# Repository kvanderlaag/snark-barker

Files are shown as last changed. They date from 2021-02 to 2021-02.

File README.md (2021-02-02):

# The Shark Barber - a silly joke that is a rebadge of the Snark Barker - a SB 1.0 Clone

## The Shark Barber
Literally all I did was change some silkscreen graphics to make the card look 
sillier. My wife misread "Snark Barker" as "Shark Barber" while I was looking 
at the PCB layout to find a component reference while building mine, and
[@leadedsolder](https://twitter.com/LeadedSolder) suggested that it needed a
cartoon of a shark on it. Otherwise, this is 100% Snark Barker and you should
check out Eric's documentation because it's fantastic.

## The Snark Barker
The Snark Barker is a 100% compatible clone of the famed SB 1.0 "Killer Card"
sound card from 1989. It implements all the features, including the digital
sound playback and recording, Ad Lib compatible synthesis, the joystick/MIDI
port, and the CMS chips (which are actually Philips SAA1099 synthesizer
devices).

Snark Barker photo

All of the components are readily available. In the bill of materials,
Mouser part numbers are listed where they are available. Chips not available
from Mouser can be purchased from a variety of sources in China.

[Schematic](https://github.com/schlae/snark-barker/blob/master/SnarkBarker.pdf)

[Bill of Materials](https://github.com/schlae/snark-barker/blob/master/SnarkBarker.csv)

Please note that the 0.1" header pins are *not* listed on the BOM. They are
standard breakaway headers (both single and double row). Jumper shunts are
also not listed on the BOM.

[Fab files](https://github.com/schlae/snark-barker/blob/master/fab/SnarkBarker.zip)

Board dimensions are 9.1 x 4.2 inches. When ordering the board, you may want
to specify a card edge bevel (fairly cheap!) and selective gold plating
(expensive!) depending on your needs. The soldermask color can be whatever
you like, but hot pink is preferred.

## The Volume Knob
There don't seem to be any off-the-shelf knobs compatible with the Alps
potentiometer. You may be able to 3D print one based on the model below.
I'd recommend using a high-resolution SLA printer like the Formlabs Form 2.

Fasten it to the potentiometer using an M1.4x0.3mm thread, 6mm long screw
(McMaster-Carr part number 91800A036 or equivalent).

Image of the volume knob

[Volume knob STEP model](https://github.com/schlae/snark-barker/blob/master/mech/vol_knob.zip)

Update: I've added a modified volume knob that may print better on FDM
printers.

[Volume knob STEP model, FDM version](https://github.com/schlae/snark-barker/blob/master/mech/vol_knob_fdm.zip)

## The ISA Card Bracket
The bracket specified in the BOM is a blank Keystone 9200 bracket. You will
need to punch or drill holes for the connectors. The KiCad board file has
detailed dimensions showing where to make the holes in the bracket.

I use a chassis nibbler tool to make the square slot for the volume knob as
well as the hole for the DA-15 joystick/MIDI connector. If you are rich,
Greenlee makes a punch for the DA-15 outline.

## The Firmware
There are two ways to get a programmed 80C51 chip for the Snark Barker. One
is to purchase a SB 2.0 DSP chip from China and put it in a 44-PLCC to
40-DIP adapter. This works fine and provides the largest feature set.

Another option is to buy a blank Atmel 89S51 (as listed in the BOM) and
program it with [this HEX file](https://github.com/schlae/snark-barker/blob/master/firmware/sb.hex).

## Assembly Notes
You may wish to socket the two CMS chips, the 80C51 microcontroller, and the
two Yamaha chips.

Be sure to add the 4.7K ohm bodge resistor on top of U5, running between
pins 4 and 14. (Shown below.)

Photo of bodge resistor

For MIDI to work properly, you'll need to solder jumper wires on the headers
marked TXD and RXD (next to the SNARK BARKER logo). Originally these two 3-pin
headers may have been used as a debug port.

Be sure to place shunts in the jumpers marked DRQ1 and JP1, to enable DMA and
the joystick, respectively. Also place shunts to configure the I/O address and
IRQ.

## Testing and Diagnostics
Test your shiny new card using your favorite PC games, or use the [SBDIAG
program that I've written](https://github.com/schlae/snark-barker/tree/master/sbdiag).

## Other Notes
Like the original SB 1.0, the Snark Barker does not need a -5V rail.

## License
This work is licensed under a Creative Commons Attribution-ShareAlike 4.0
International License. See [https://creativecommons.org/licenses/by-sa/4.0/](https://creativecommons.org/licenses/by-sa/4.0/).

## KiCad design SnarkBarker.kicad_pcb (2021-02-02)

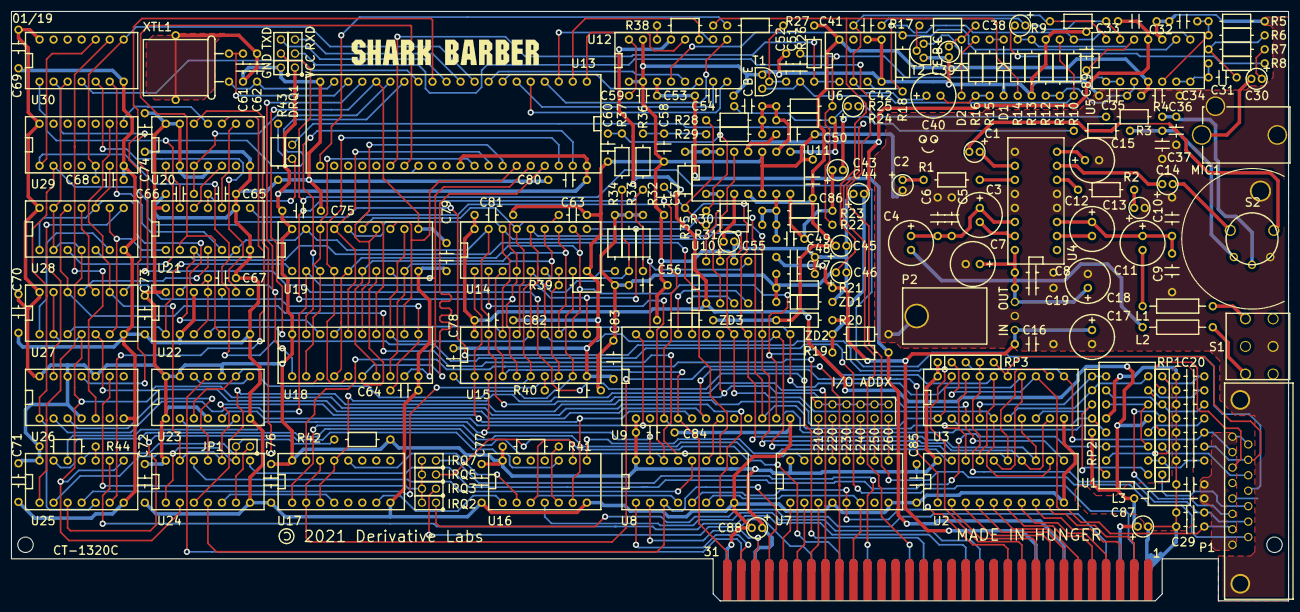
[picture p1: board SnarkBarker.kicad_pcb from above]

Board: 2 copper layers, 231.1 x 106.7 mm, 193 parts (0 on the bottom side), 215 nets.

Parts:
C1, C14, C30, C38, C39, C42, C43, C44, C45, C46, C55, C87, C88: 10uF 16V; SB_C_RADIAL_75_150
C2, C13: 47uF 16V; SB_C_RADIAL_75_150
C3, C7, C12, C15, C17, C18, C40: 100uF 16V; SB_C_RADIAL_100_320
C4, C11: 470uF 16V; SB_C_RADIAL_100_320
C5, C6, C8, C9, C10, C16, C19, C33, C34, C47, C48, C50, C53, C56, C69, C70, C71, C72, C73, C74, C75, C76, C77, C80, C81, C82, C83, C84, C85, C86, C89: 0.1u; SB_C_AXIAL_275
C20, C21, C22, C23, C24, C25, C26, C27, C28, C29: 0.01u; SB_C_DISC_200
C31, C36, C37, C49, C54, C63, C78: 1000p; SB_C_DISC_200
C32, C35, C52, C64, C79: 330p; SB_C_DISC_200
C41: 47; SB_C_DISC_200
C51, C58, C60: 2200p; SB_C_DISC_200
C57: 4700p; SB_C_DISC_200
C59: 47p; SB_C_DISC_200
C61, C62: 30p; SB_C_DISC_200
C65, C68: 270p; SB_C_DISC_200
C66: 680p; SB_C_DISC_200
C67: 470p; SB_C_DISC_200
D1, D2: 1N4148; SB_D_AXIAL_400
DRQ1: DMA ENABLE JUMPER; SB_HDR_1X2
IO1: I/O ADDX; SB_HDR_2X6
IRQ2, IRQ3, IRQ5, IRQ7: Conn_02x01; SB_HDR_1X2
J1: Bus_ISA_8bit; BUS_PC
J2: Bracket Mount; SB_MH_125
JP1: JOYSTICK EN; SB_HDR_1X2
L1, L2, L3: ?; SB_L_AXIAL_500
MIC1: Microphone; SB_MJ-3536N
P1: Joystick/MIDI; SB_DB15_152-3415
P2: L7809; SB_TO220
R1, R2: 270; SB_R_AXIAL_400
R3, R4, R8, R23, R24, R34, R36, R37, R40: 10K; SB_R_AXIAL_400
R5, R9, R12: 470K; SB_R_AXIAL_400
R6, R7, R11: 68K; SB_R_AXIAL_400
R10: 39K; SB_R_AXIAL_400
R13: 39.0K 1%; SB_R_AXIAL_400
R14: 100.0K 1%; SB_R_AXIAL_400
R15, R16: 470; SB_R_AXIAL_400
R17: 33K; SB_R_AXIAL_400
R18: 1.5K 1%; SB_R_AXIAL_400
R19, R20, R21: 390; SB_R_AXIAL_400
R22, R25, R27: 27K; SB_R_AXIAL_400
R26, R39, R41, R42, R44: 4.7K; SB_R_AXIAL_400
R28, R31: 15K; SB_R_AXIAL_400
R29, R30: 47K; SB_R_AXIAL_400
R32, R33: 1.5K; SB_R_AXIAL_400
R35: 2.2K; SB_R_AXIAL_400
R38: 2.70K 1%; SB_R_AXIAL_400
R43: 1K; SB_R_AXIAL_400
RP1: 2.2K; SB_RP_4B
RP2, RP3: 1K; SB_RP_4C
RXD1: Conn_01x03; SB_HDR_1X3
S1: OUT; SB_SJ1-3553
S2: ALPS_RK08H_DUAL; SB_ALPS_RK08_DUAL
T1, T2: 2N3904; SB_TO92
TXD1: Conn_01x03; SB_HDR_1X3
U1: NE558; SB_DIP16_300
U2: 74LS245; SB_DIP20_300
U3: 74LS244; SB_DIP20_300
U4: TEA2025B; SB_DIP16_300
U5: LM324; SB_DIP14_300
U6: LM393; SB_DIP8_300
U7, U8: 74LS138; SB_DIP16_300
U9: YM3812; SB_DIP24_600
U10: YM3014B; SB_DIP8_300
U11: NJM3403A; SB_DIP14_300
U12: MC1408_DIP; SB_DIP16_300
U13: 805X; SB_DIP40_600
U14, U15: SAA1099; SB_DIP18_300
U16, U25, U28: 74LS08; SB_DIP14_300
U17: 74LS139; SB_DIP16_300
U18, U19: 74LS374; SB_DIP20_300
U20, U22, U23, U26: 74LS74; SB_DIP14_300
U21: 74LS125; SB_DIP14_300
U24, U27, U30: 74LS32; SB_DIP14_300
U29: 74LS14; SB_DIP14_300
XTL1: 12MHz; SB_XTAL_HC49U_RA
ZD1, ZD2, ZD3: 5.1V; SB_D_AXIAL_400_ALT

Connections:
+5VA: C34.1, C45.1, C86.1, R20.2, R26.1, U5.4, U6.8, U11.4, ZD3.1
+5VD: C46.1, C47.1, C56.1, C83.1, R14.1, R21.2, R32.2, R33.2, R34.1, R38.2, R39.1, R40.1, ZD1.1
+9VA: C7.1, C8.1, C18.1, C19.1, P2.3, U4.16
+12V: C16.1, C17.1, C48.1, J1.9, P2.1, R20.1, R21.1
-5VA: C33.1, C44.2, C50.1, R19.1, U5.11, U11.11, ZD2.2
-12V: C53.1, C59.2, J1.7, R19.2, U12.3
/1xx000xxxx: U7.15, U17.1
/A0: J1.62, U9.4, U14.3, U15.3
/A1: J1.61, U8.1
/A2: J1.60, U8.2
/A3: J1.59, U8.3, U24.4
/A4: J1.58, U7.1
/A5: J1.57, U7.2
/A6: J1.56, U7.3
/A7: J1.55, U17.3, U17.13
/A8: J1.54, U17.2, U17.14
/A9: J1.53, U7.6, U8.6
/AEN: J1.42, U7.5, U8.5
/BUSRESET: J1.2, U29.1, U30.10
/BUTTON1: C24.1, P1.2, RP3.3, U3.11
/BUTTON2: C29.1, P1.7, RP3.2, U3.13
/BUTTON3: C28.1, P1.14, RP3.4, U3.17
/BUTTON4: C25.1, P1.10, RP3.5, U3.15
/CLK_3M579: U9.24, U23.5
/CLK_7M159: U14.8, U15.8, U23.3, U23.9
/CLK_14M318: J1.30, U23.11
/CMS1-6_~CS: U8.15, U15.2, U25.12
/CMS7-12_~CS: U8.14, U14.2, U25.13
/D0: U2.18, U3.18, U9.10, U14.10, U15.10, U18.3, U19.2, U26.2
/D1: U2.17, U3.16, U9.11, U14.11, U15.11, U18.4, U19.5
/D2: U2.16, U3.14, U9.13, U14.12, U15.12, U18.7, U19.6
/D3: U2.15, U3.12, U9.14, U14.13, U15.13, U18.8, U19.9
/D4: U2.14, U3.9, U9.15, U14.14, U15.14, U18.13, U19.12
/D5: U2.13, U3.7, U9.16, U14.15, U15.15, U18.14, U19.15
/D6: U2.12, U3.5, U9.17, U14.16, U15.16, U18.17, U19.16
/D7: U2.11, U3.3, U9.18, U14.17, U15.17, U18.18, U19.19, U21.3, U21.6
/DAC0: U12.12, U13.1
/DAC1: U12.11, U13.2
/DAC2: U12.10, U13.3
/DAC3: U12.9, U13.4
/DAC4: U12.8, U13.5
/DAC5: U12.7, U13.6
/DAC6: U12.6, U13.7
/DAC7: U12.5, U13.8
/DAV_DSP: U13.28, U22.9, U30.5
/DAV_PC: U13.27, U21.2, U22.5
/DAV_~CS: U8.7, U27.5
/DB0: J1.40, U2.2
/DB1: J1.39, U2.3
/DB2: J1.38, U2.4
/DB3: J1.37, U2.5
/DB4: J1.36, U2.6
/DB5: J1.35, U2.7
/DB6: J1.34, U2.8
/DB7: J1.33, U2.9
/DD0: U13.39, U18.2, U19.3
/DD1: U13.38, U18.5, U19.4
/DD2: U13.37, U18.6, U19.7
/DD3: U13.36, U18.9, U19.8
/DD4: U13.35, U18.12, U19.13
/DD5: U13.34, U18.15, U19.14
/DD6: U13.33, U18.16, U19.17
/DD7: U13.32, U18.19, U19.18
/DIGITAL_OUT: C51.1, R22.2, R25.2, U5.1, U5.2
/DREQUEST: C66.1, U13.15, U20.3
/DRQ1: DRQ1.2, J1.18
/DSPRD_~CS: U8.10, U28.5
/DSPRST_~CS: U8.12, U24.12
/DSPWR_~CS: U8.9, U27.12, U28.12
/DSP_BUSY: U13.13, U30.4
/FM_~CS: U8.11, U9.7
/IO_READY: J1.41, U21.8
/IREQUEST: U13.12, U26.11
/IRQ2: IRQ2.1, J1.4
/IRQ3: IRQ3.1, J1.25
/IRQ5: IRQ5.1, J1.23
/IRQ7: IRQ7.1, J1.21
/JOYSTICK_~CS: JP1.2, R42.2, U24.1, U24.9, U25.2
/MIC_COMP: R26.2, U6.1, U13.26
/MIDI_IN: P1.15, RXD1.2
/MIDI_OUT: P1.12, TXD1.2
/MUTE_EN: R27.1, U13.21
/OPL2: C57.1, R28.2, R31.2, R35.1
/RESET: C68.1, U13.9, U29.5, U30.8
/SAA_L: C60.1, R30.2, R37.1
/SAA_R: C58.1, R29.2, R36.1
/X1: P1.3, RP1.7
/X2: P1.11, RP1.3
/Y1: P1.6, RP1.5
/Y2: P1.13, RP1.1
/~100jjjxxxx: U16.2, U17.12
/~100000xxxx: U17.4, U24.5
/~111000xxxx: U16.1, U17.7
/~CARD_SELECTED: U8.4, U16.3, U16.9
/~DACK1: J1.17, U30.2
/~DB_EN: U2.19, U16.8
/~DMAOUT: U25.1, U28.2, U28.4, U28.13, U30.3
/~DMA_EN: U13.14, U21.13, U30.1
/~DSP_READ: U13.17, U18.1, U22.13
/~DSP_WRITE: C79.1, U13.16, U19.11, U22.4
/~IC: U1.13, U9.3, U25.5, U26.1, U29.2
/~IOR: J1.14, U25.9
/~IOW: J1.13, U16.4
/~ISA_RD: U19.1, U22.1, U27.3
/~ISA_WR: C64.1, U18.11, U22.10, U27.8
/~RD: U2.1, U9.6, U24.2, U25.8, U27.2, U27.4, U27.13
/~RD_DAV: U21.1, U27.6, U28.9
/~RESET: C67.1, U22.3, U22.11, U28.1, U28.10, U29.6
/~WR: U9.5, U14.1, U15.1, U16.6, U24.10, U24.13, U27.9, U29.9
GND: C61.2, C62.2, C64.2, C65.2, C66.2, C67.2, C68.2, C69.2, C70.2, C71.2, C72.2, C73.2, C74.2, C75.2, C76.2, C77.2, C79.2, C80.2, C84.2, C85.2, C88.2, J1.31, R43.2, TXD1.1, U2.10, U3.10, U7.4, U7.8, U8.8, U9.12, U13.20, U16.7, U17.8, U18.10, U19.10, U20.7, U21.7, U21.9, U22.2, U22.7, U22.12, U23.7, U24.7, U25.7, U26.7, U27.7, U28.7, U29.7, U30.7, XTL1.2, XTL1.4
GNDA: C2.2, C5.2, C6.2, C7.2, C8.2, C9.2, C10.2, C13.2, C15.2, C16.2, C17.2, C18.2, C19.2, C20.2, C21.2, C22.2, C23.2, C24.2, C25.2, C26.2, C27.2, C28.2, C29.2, C32.1, C33.2, C34.2, C35.2, C36.2, C37.1, C39.2, C44.1, C45.2, C46.2, C47.2, C48.2, C50.2, C52.1, C53.2, C55.2, C56.2, C57.2, C58.2, C60.2, C63.2, C78.2, C81.2, C82.2, C83.2, C86.2, C87.2, C89.2, D1.2, J1.1, J2.1, MIC1.2, MIC1.3, P1.0, P1.4, P1.5, P2.2, R5.2, R12.2, R13.2, S1.3, S2.3, T1.1, T2.1, U1.12, U4.4, U4.5, U4.9, U4.12, U4.13, U5.10, U6.4, U6.5, U6.6, U10.6, U11.5, U11.10, U12.1, U12.2, U12.15, U14.9, U15.9, ZD1.2, ZD2.1, ZD3.2
unnamed: C1.1, U4.10
unnamed: C1.2, S2.2A
unnamed: C2.1, R1.2
unnamed: C3.1, C4.1, C5.1, C6.1, U4.14
unnamed: C3.2, U4.15
unnamed: C4.2, L2.1
unnamed: C9.1, C10.1, C11.1, C12.1, U4.3
unnamed: C11.2, L1.1
unnamed: C12.2, U4.2
unnamed: C13.1, R2.2
unnamed: C14.1, U4.7
unnamed: C14.2, S2.2B
unnamed: C15.1, U4.8
unnamed: C20.1, RP1.8, U1.15
unnamed: C21.1, RP1.4, U1.7
unnamed: C22.1, RP1.6, U1.10
unnamed: C23.1, U1.4
unnamed: C26.1, RP1.2, U1.2
unnamed: C27.1, L3.2, P1.1, P1.8, P1.9
unnamed: C30.1, R7.1
unnamed: C30.2, MIC1.1
unnamed: C31.1, R8.2, U5.6, U5.7
unnamed: C31.2, R6.1, R7.2
unnamed: C32.2, R5.1, R6.2, U5.5
unnamed: C35.1, R11.1, R12.1, U5.3
unnamed: C36.1, R4.1, S2.1A
unnamed: C37.2, R3.1, S2.1B
unnamed: C38.1, C41.2, R9.2, U5.13
unnamed: C38.2, R8.1, T2.3
unnamed: C39.1, D2.1, R17.2
unnamed: C40.1, C41.1, R9.1, U5.14, U6.2
unnamed: C40.2, R15.2, R16.2
unnamed: C42.1, C54.2, R24.1, U11.8
unnamed: C42.2, R4.2
unnamed: C43.1, C49.1, R23.1, U11.7
unnamed: C43.2, R3.2
unnamed: C49.2, R22.1, R23.2, R30.1, R31.1, U11.6
unnamed: C51.2, R10.1, R11.2, T1.3
unnamed: C52.2, R27.2, T1.2
unnamed: C54.1, R24.2, R25.1, R28.1, R29.1, U11.9
unnamed: C55.1, U10.7, U11.3
unnamed: C59.1, U12.16
unnamed: C61.1, U13.18, XTL1.3
unnamed: C62.1, U13.19, XTL1.1
unnamed: C63.1, R32.1, R36.2, U14.4, U15.4
unnamed: C65.1, DRQ1.1, R43.1, U21.11
unnamed: C78.1, R33.1, R37.2, U14.5, U15.5
unnamed: C89.1, R13.1, R14.2, U5.12
unnamed: D1.1, R15.1
unnamed: D2.2, R16.1
unnamed: IO1.1, U7.14
unnamed: IO1.3, U7.13
unnamed: IO1.5, U7.12
unnamed: IO1.7, U7.11
unnamed: IO1.9, U7.10
unnamed: IO1.2, IO1.4, IO1.6, IO1.8, IO1.10, IO1.12, U17.15
unnamed: IO1.11, U7.9
unnamed: IRQ2.2, IRQ3.2, IRQ5.2, IRQ7.2, U26.9
unnamed: JP1.1, U24.6
unnamed: L1.2, S1.1
unnamed: L2.2, S1.2
unnamed: R1.1, U4.11
unnamed: R2.1, U4.6
unnamed: R10.2, R18.2, U5.8, U6.3
unnamed: R17.1, T2.2
unnamed: R18.1, U5.9, U12.4
unnamed: R34.2, U14.6
unnamed: R35.2, U11.13, U11.14
unnamed: R38.1, U12.14
unnamed: R39.2, U14.7, U15.7, U25.4
unnamed: R40.2, U15.6
unnamed: R41.2, U16.5
unnamed: R44.2, U25.10
unnamed: RP2.2, U1.16, U3.2
unnamed: RP2.3, U1.1, U3.8
unnamed: RP2.4, U1.8, U3.6
unnamed: RP2.5, U1.9, U3.4
unnamed: RXD1.3, U13.10
unnamed: TXD1.3, U13.11
unnamed: U1.3, U1.6, U1.11, U1.14, U24.8
unnamed: U10.2, U11.12
unnamed: U9.20, U10.3
unnamed: U9.21, U10.4
unnamed: U9.23, U10.5
unnamed: U10.8, U11.1, U11.2
unnamed: U16.10, U25.3
unnamed: U20.1, U28.3
unnamed: U20.5, U21.12
unnamed: U20.9, U21.10
unnamed: U20.10, U25.6
unnamed: U20.11, U29.8
unnamed: U20.12, U25.11
unnamed: U21.4, U27.11
unnamed: U21.5, U30.6
unnamed: U23.2, U23.6
unnamed: U23.8, U23.12
unnamed: U3.1, U3.19, U24.3
unnamed: U24.11, U26.3
unnamed: U26.5, U30.9
unnamed: U26.13, U28.8
unnamed: U27.1, U28.6
unnamed: U27.10, U28.11
VCC: C69.1, C70.1, C71.1, C72.1, C73.1, C74.1, C75.1, C76.1, C77.1, C80.1, C84.1, C85.1, C88.1, J1.29, R41.1, R42.1, R44.1, RP3.1, RXD1.1, U2.20, U3.20, U7.16, U8.16, U9.1, U13.31, U13.40, U16.14, U17.16, U18.20, U19.20, U20.2, U20.4, U20.13, U20.14, U21.14, U22.14, U23.1, U23.4, U23.10, U23.13, U23.14, U24.14, U25.14, U26.4, U26.10, U26.12, U26.14, U27.14, U28.14, U29.14, U30.14
VDDA: C81.1, C82.1, C87.1, J1.3, L3.1, RP2.1, U1.5, U10.1, U12.13, U14.18, U15.18

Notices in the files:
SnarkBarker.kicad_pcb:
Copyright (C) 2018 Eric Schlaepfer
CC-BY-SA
